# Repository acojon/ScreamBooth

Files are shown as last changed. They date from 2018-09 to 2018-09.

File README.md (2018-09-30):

# ScreamBooth

Here is a potato quality video showing how the Scream Booth works.
<a href="http://www.youtube.com/watch?feature=player_embedded&v=JRlw0t9dDx0" target="_blank">A Fun Low Quality Youtube Video</a>

A sound activated trigger for my Canon DSLR cameras.  I use this for our annual Halloween Party to setup a photo booth.  The photo booth is sound powered, you have to make a loud sharp sound like a scream, clap, stomp, etc.  The sound then trips the camera and the strobe light letting people take pictures of themselves.  Thus the name "Scream Booth"  It's always been a hit at our halloween party, but in 2017, I ran into a problem.

The scream booth was made possible by a company called Trigger Trap, and a product they sold.  The company sold a dongle, one side connected to your camera's remote trigger, the other connected to the headphone port on your smart phone.  You would download a free app onto your smart phone.  The Trigger Trap app had a number of options for triggering a camera, I used the trigger by sound option to run the Scream Booth.  The idea for the Scream Booth came from one of their blog posts.  It looked like so much fun, I setup one for our Halloween party and it was a hit.

In 2017, the hardware dongle failed, whenever it was plugged into the camera, the shutter on the camera would continuously activate.  This was not a good situation.  Around this time smart phone manufacturers had moved away from installing a headphone jack on their smart phones.  Trigger Trap had gone out of business and you couldn't easily buy a replacement dongle.  Frustrated by these technical failures, I didn't setup a photo booth for that year's halloween party.  This... was a mistake :)  After the party, a couple friends suggested that building a DIY sound trigger was a relatively easy electronics task and encouraged me to try and build a replacement.

I've setup this GitHub repository to share the code, the PCB files, photos, etc. so that if you too would like to setup your own sound powered camera trigger, you can use these resources to help get your own setup.

## Parts List

* 1 x [Adafruit Trinket M0](https://www.adafruit.com/product/3500)
* 1 x [MAX4466 Microphone](https://www.adafruit.com/product/1063)
* 1 x [Simple Shutter Release Cable](https://www.amazon.com/gp/product/B00C0K2PQU/ref=oh_aui_search_detailpage?ie=UTF8&psc=1)
* 1 x [10K Potentiometer](https://www.adafruit.com/product/562)
* 1 x 1000uF Capacitor
* 3 x 100nF Capacitors
* 1 x [Diode](https://www.digikey.com/product-detail/en/on-semiconductor/1N4148TR/1N4148FSCT-ND/9356376)
* 1 x [Signal Relay](https://www.digikey.com/products/en?keywords=ec2-3nu)
* 1 x NPN Transistor. I used this [2N3094](https://www.digikey.com/product-detail/en/on-semiconductor/2N3904BU/2N3904FS-ND/1413)
* 1 x 1K Resistor
* 1 x 10K Resistor
* 1 x Red LED
* 1 x Green LED

Optional Parts:

* Header Pins
* 5v Power Supply for Trinket & Power Cable.  Perhaps a jack to connect/disconnect the power cable
* Fuse
* On/Off Switch
* Connector for Shutter Release cable to Project box (I used a 3.5mm headphone jack and plug)
* Project Box
* Momentary switch to use as reset button

## How does it work

The Scream Booth works by using a microphone to listen to the current sound in the room.  The output is run into a micro controller.  In this case I'm using an Adafruit Trinket M0, but just about any micro controller should work. The micro controller compares the current sound level to a threshold value.  The threshold value is set by the 10k potentiometer. If the current sound level is higher than the threshold level, the micro controller sets the LED and Camera PINS to HIGH for 500 milliseconds (1/2 a second.) This turns on the transistor, which turns on the relay.  The relay connects the camera's ground and "Full Press" pins together which triggers the shutter on the camera.

### Things I learned picking a microphone breakout board

The most important thing I learned while testing microphone breakout boards was to test the microphone and see if there is a "loud noise" cutout.  If the microphone mutes the output (or does some clever filtering to keep the loud noise from appearing in the output) then this microphone isn't going to work for the Scream Booth.

### Things I learned about camera remote trigger jacks

The camera I use for the Scream Booth is a Canon DSLR.

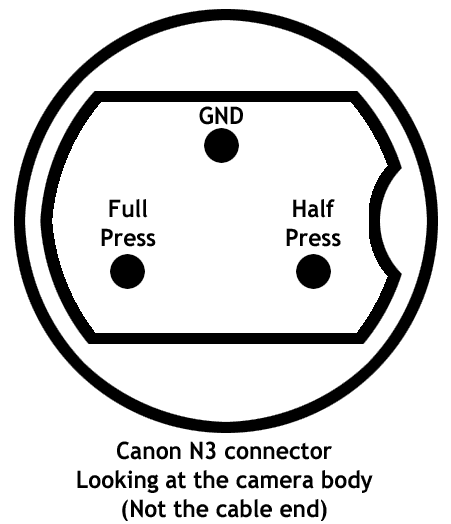
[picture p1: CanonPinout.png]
CannonPinout


The manufactured remote controls work by connecting the Half Press, or Full Press pins to the camera's ground pin.  I ordered an inexpensive remote trigger from Amazon and took it apart to confirm I understood the pinout and the behavior of the remote trigger cable.  Different camera manufacturers have different types of connectors to their remote trigger, but many followed the same approach: Connect pin to camera ground to trigger the camera shutter.

### Things I learned about using a relay

In this project, I used a relay to trigger the camera.  You could use a opto-isolator to replace the relay.  If you know more than I do about electronics (not hard, I'm only a hobbyist) then there may be other options to momentarily connect the two pins on the camera.  I'm not here to judge :)  The relay's coil is connected to 3.3v, and to an NPN transistor configured as a low side switch.  There's a pull down resistor on the transistor's gate pin.  The Trinket can trigger the transistor.  There's a flyback diode in parallel with the relay coil to keep the transistor safe.

### Things I learned about using an Adafruit Trinket M0

I used this micro controller because it's inexpensive, and because I have a couple on hand :) You can use a different micro controller, or you can skip the micro controller if you know how to build this sort of trigger without one.

## PCB

This was the first PCB I designed.  It actually took three tries to get a board that worked.  If you are using the same parts that I'm using, please feel free to use the Scream Booth Gerber Files.zip to order some PCBs of your own. :)

## Final Disclaimer

I'm not an electronics expert, I have a hobby level of understanding about electronics.  If you see a mistake, please let me know.  If you know how to modify something, or alter the parts, etc., please do.

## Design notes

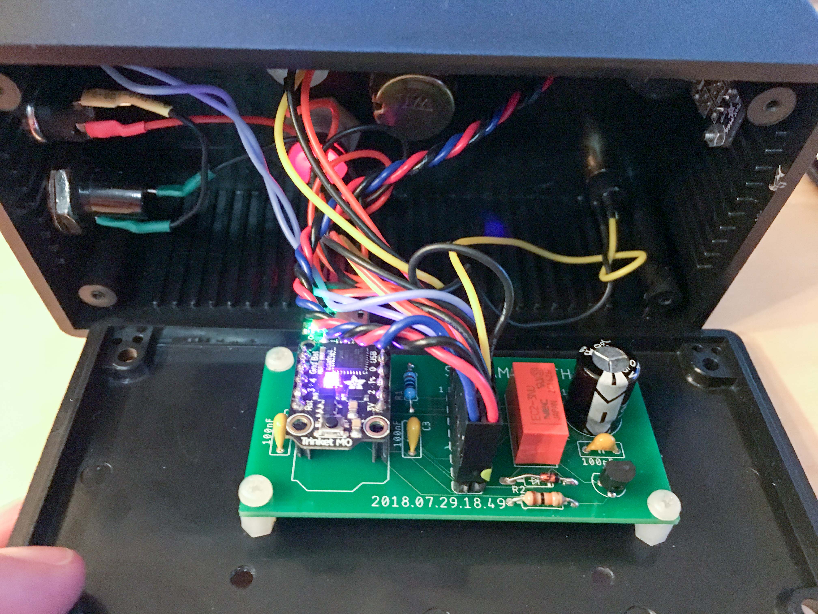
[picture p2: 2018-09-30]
Photos/2018-08-08 18.09.33.jpg

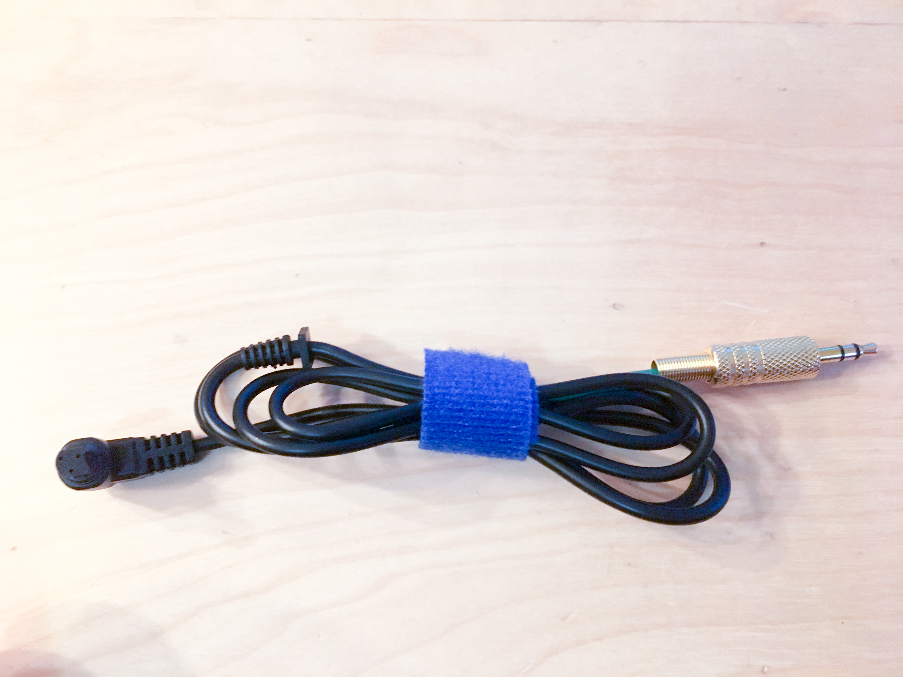
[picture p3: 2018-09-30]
Photos/2018-07-08 09.28.32-3.jpg

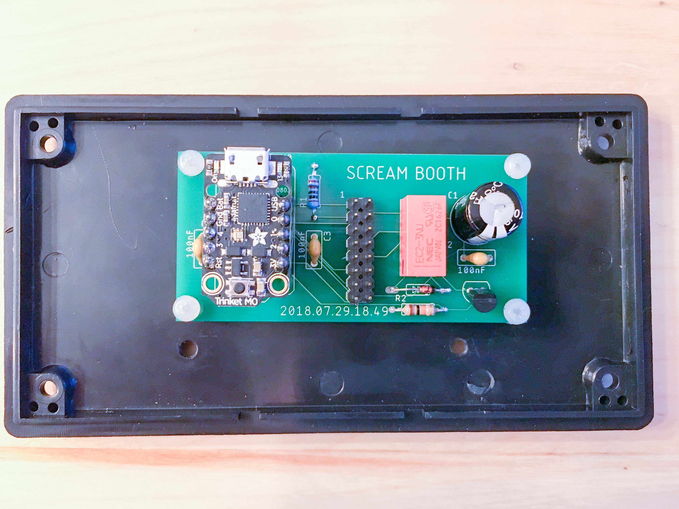
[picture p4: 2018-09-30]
Photos/2018-08-08 18.08.23.jpg

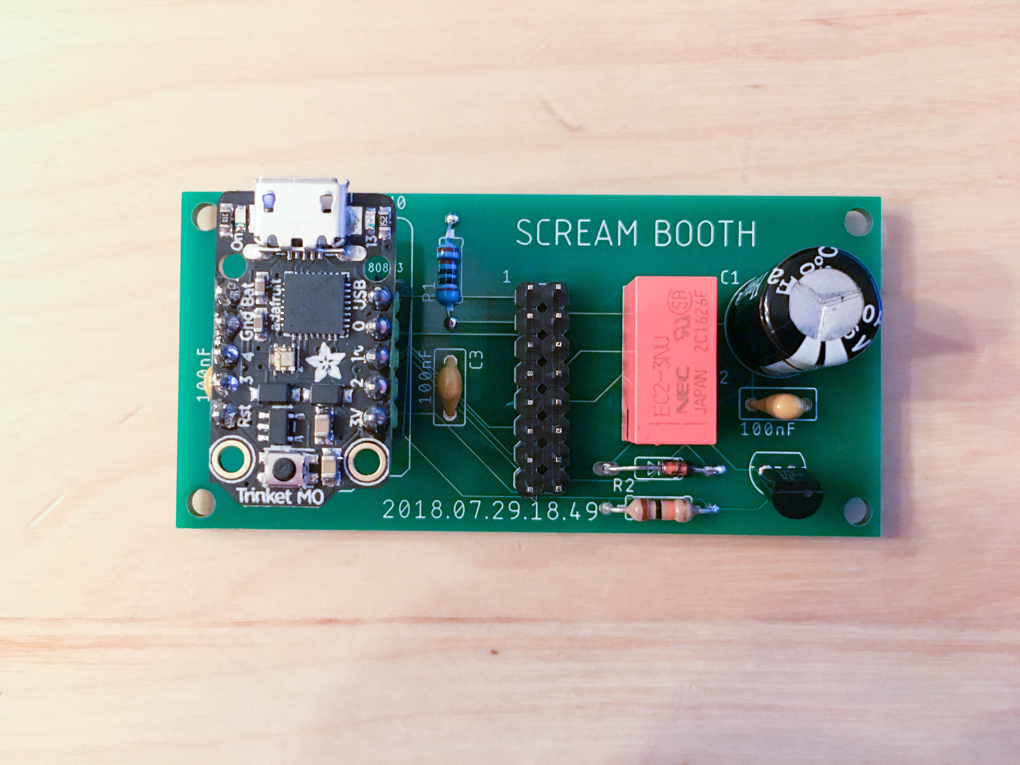
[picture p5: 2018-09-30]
Photos/2018-08-08 17.53.20.jpg

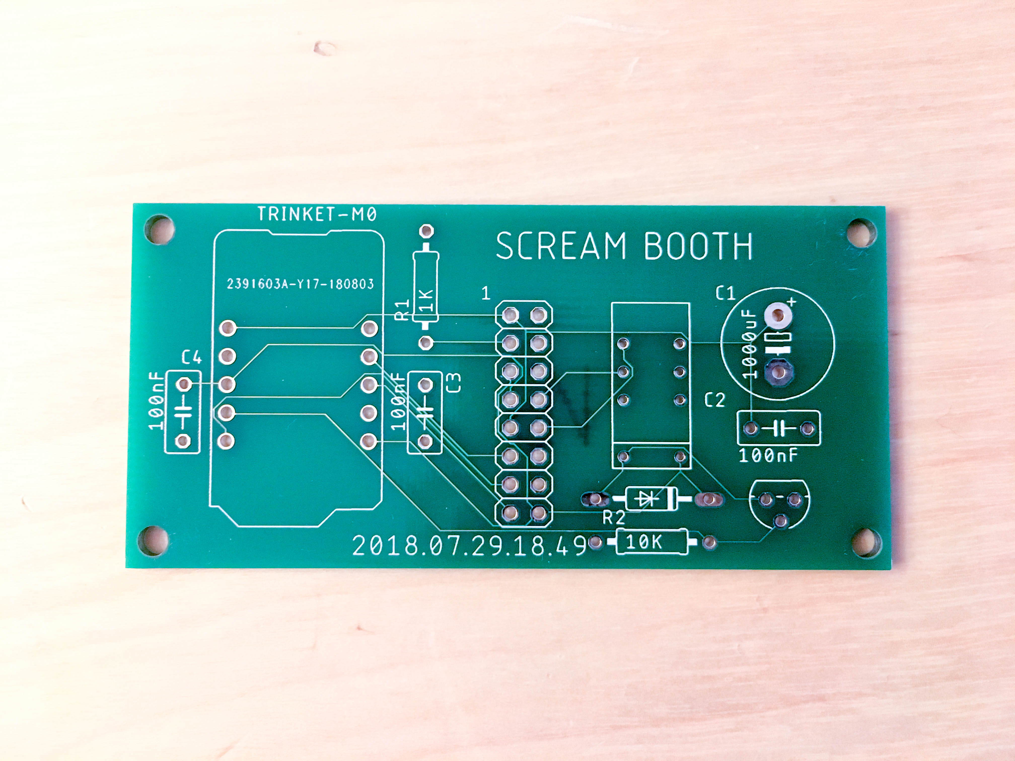
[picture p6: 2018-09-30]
Photos/2018-08-08 17.52.18.jpg

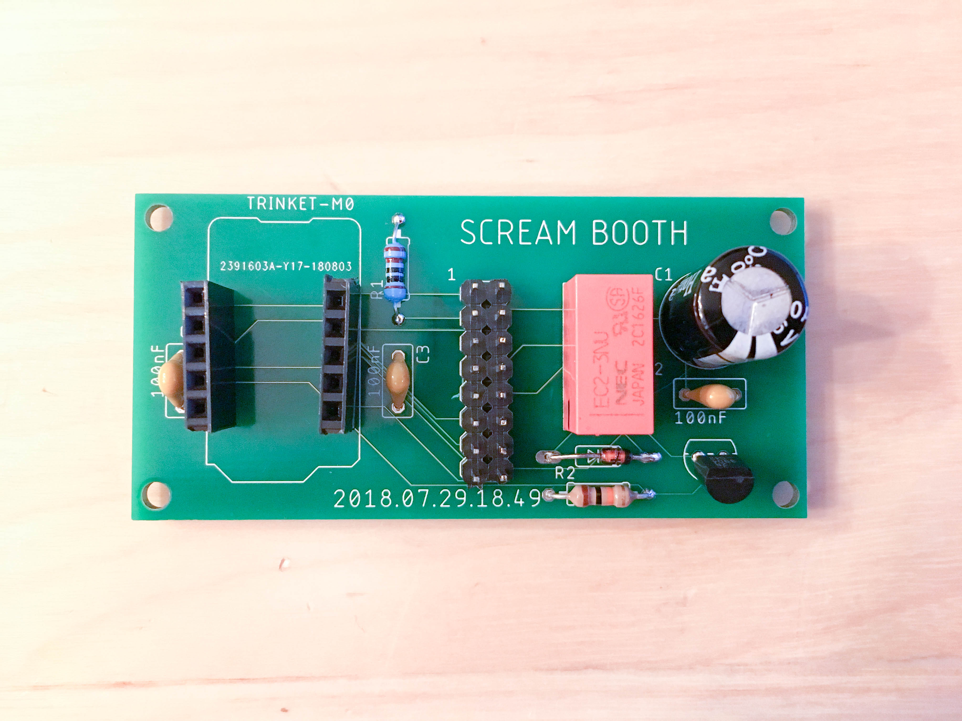
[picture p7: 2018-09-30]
Photos/2018-08-08 17.52.38.jpg

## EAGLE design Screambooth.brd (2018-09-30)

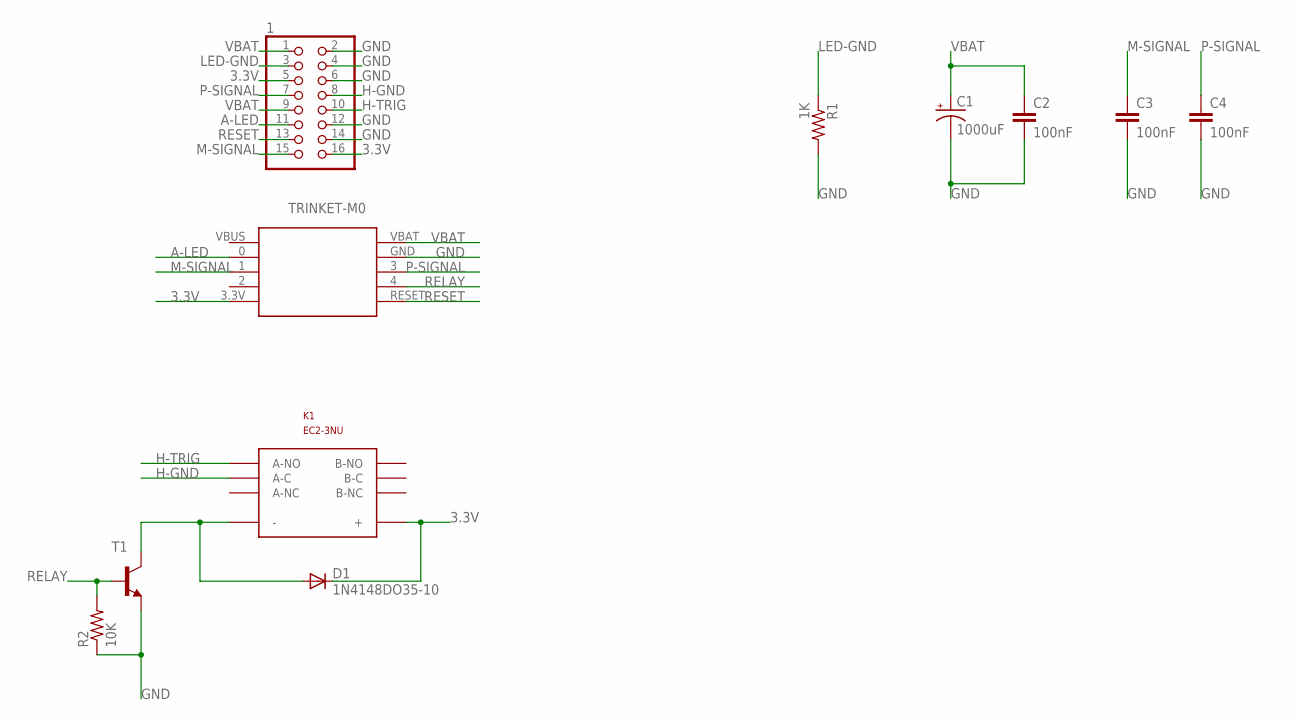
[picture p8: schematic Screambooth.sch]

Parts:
1: PINHD-2X8; 2X08
C1: 1000uF; E5-10,5
C2, C3, C4: 100nF; C050-030X075
D1: 1N4148DO35-10; DO35-10
K1: EC2-3NU; EC2-RELAY
R1: 1K; 0207/10
R2: 10K; 0207/10
T1: 2N3904; TO92
TRINKET-M0: TRINKET-M0

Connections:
3.3V: 1.5, 1.16, D1.C, K1.+, TRINKET-M0.3.3V
A-LED: 1.11, TRINKET-M0.0
GND: 1.2, 1.4, 1.6, 1.12, 1.14, C1.-, C2.2, C3.2, C4.2, R1.2, R2.1, T1.3 (E), TRINKET-M0.GND
H-GND: 1.8, K1.A-C
H-TRIG: 1.10, K1.A-NO
LED-GND: 1.3, R1.1
M-SIGNAL: 1.15, C3.1, TRINKET-M0.1
unnamed: D1.A, K1.-, T1.1 (C)
P-SIGNAL: 1.7, C4.1, TRINKET-M0.3
RELAY: R2.2, T1.2 (B), TRINKET-M0.4
RESET: 1.13, TRINKET-M0.RESET
VBAT: 1.1, 1.9, C1.+, C2.1, TRINKET-M0.VBAT

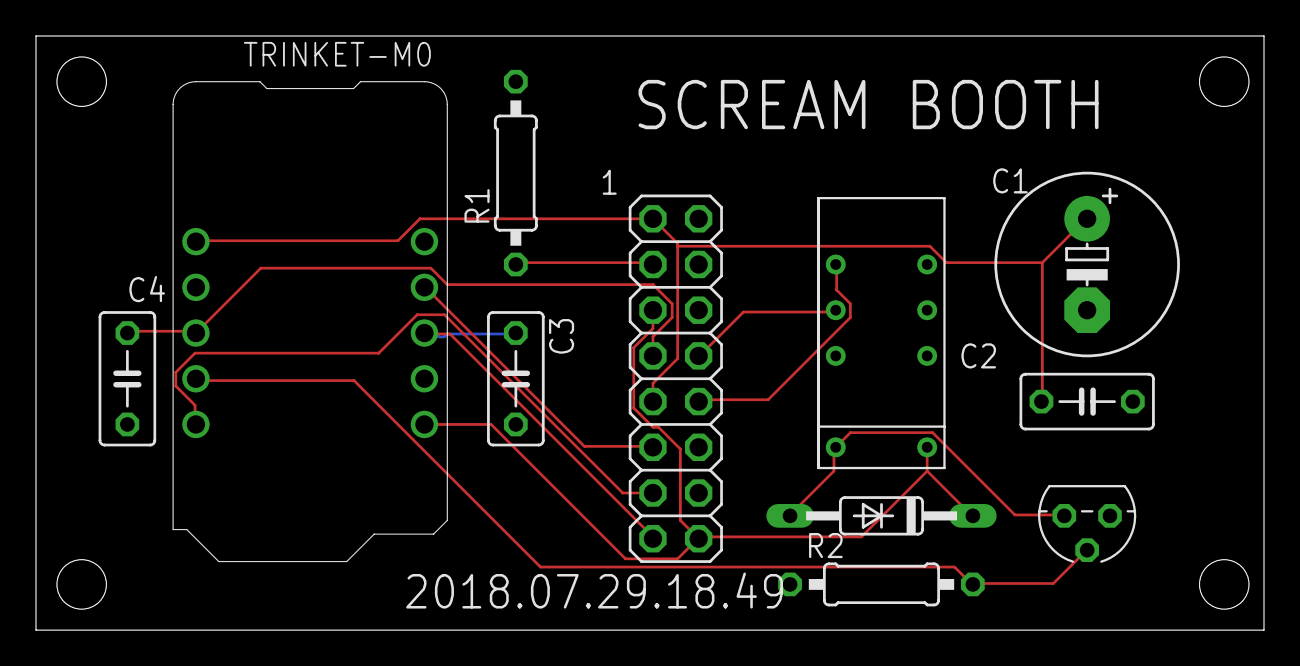
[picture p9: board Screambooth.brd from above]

Board: 2 copper layers, 68.2 x 33.0 mm, 11 parts (0 on the bottom side), 12 nets.

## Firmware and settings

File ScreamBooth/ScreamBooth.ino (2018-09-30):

// For Arduino Uno
//int cameraPin = PD4;
//int ledPin = PD2;
//int potentiometerPin = A1;
//int sensorPin = A0;

//// For Adafruit Trinket M0
//int cameraPin = A3;
//int ledPin = A4;
//int potentiometerPin = A2;
//int sensorPin = A0;

// For Adafruit Trinket M0
int cameraPin = A3;
int ledPin = A2;
int potentiometerPin = A4;
int sensorPin = A0;

int soundVolume = 0;
int triggerLevel = 0;

void setup() {
  // put your setup code here, to run once:
  Serial.begin(115200);
  Serial.println("Starting");
  pinMode(cameraPin, OUTPUT);
  pinMode(ledPin, OUTPUT);
  digitalWrite(ledPin, LOW);
  digitalWrite(cameraPin, LOW);
}

void loop() {
  // put your main code here, to run repeatedly:
  soundVolume = analogRead(sensorPin);
  triggerLevel = analogRead(potentiometerPin);
  Serial.print(soundVolume);
  Serial.print("\t");
  Serial.println(triggerLevel);
  if (soundVolume > triggerLevel)
  {
    digitalWrite(cameraPin, HIGH);
    digitalWrite(ledPin, HIGH);
    delay(500);
    digitalWrite(cameraPin, LOW);
    digitalWrite(ledPin, LOW);
    delay(100);
  }
  //  delay(5);
}

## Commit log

2018-09-30 Add Arduino Sketch
2018-09-30 Add Eagle Schematic and Board
    [DRILEGEND.CFG, Screambooth.brd, Screambooth.sch]
2018-09-30 Add Files for Ordering PCB
    These are the files I uploaded to JLBPCB.com to order the PCBs.
2018-09-30 Add Camera Pinout diagram
